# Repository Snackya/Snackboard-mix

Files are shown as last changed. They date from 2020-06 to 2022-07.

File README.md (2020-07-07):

# Snackboard µX - A DIY audio mixer for deej
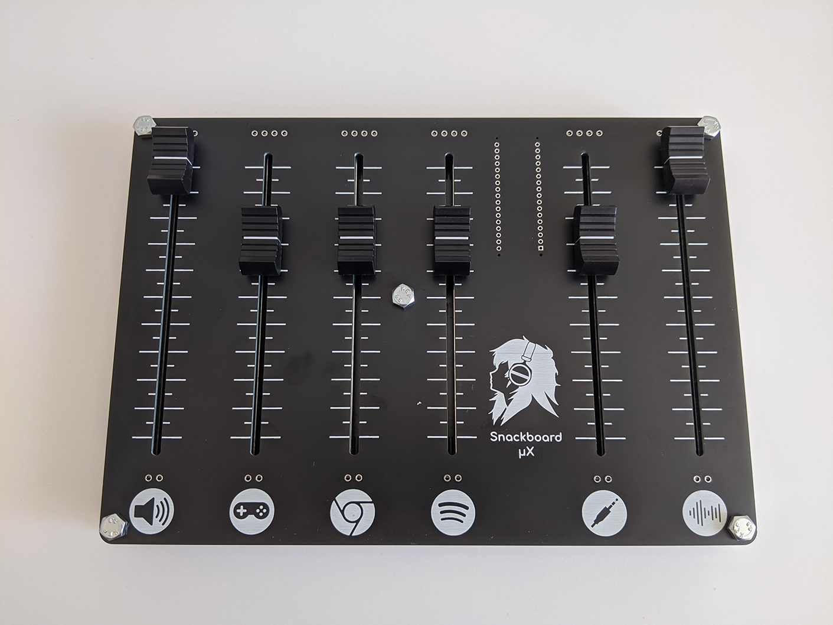
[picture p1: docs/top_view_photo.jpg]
Snackboard photo


## Description
The Snackboard µX (mix/myx) is a PCB to control application volumes on Linux/Windows using [deej](https://github.com/omriharel/deej).
It is powered by an Arduino Micro over USB and utilises 6 sliders to control the audio volume of the software configured in deej. The microcontroller reads the current state via a 10bit ADC and sends a value of 0-1023 to the PC and deej via serial.

The goal of this build was to create a mixer without any need for a 3D-printer, mill or any kind of casing. It takes advantage of the fact, that most PCB manufacturers only ship 5 prototype board minimum and uses one of them for part assembly and another for a faceplate. All the tracks for connecting parts are routed on the bottom copper layer, so the front paste and silk layers stay clean.

## Specifications
- 222 x 156 x 25 mm
- 6 sliders
- powered via Micro-USB
- [deej](https://github.com/omriharel/deej)

## Parts
- 1x Arduino Micro
- 6x Alps sliding potentiometers, linear, RSA0N12-LIN10K (most alps sliders should work. make sure they are linear and have the same footprint)
- 5x M4 bolts
- 20x M4 nuts

## Usage
Just submit the files in /gerber/ to your preferred PCB manufacturer. (Most manufacturers prefer a .zip archive of these files.)

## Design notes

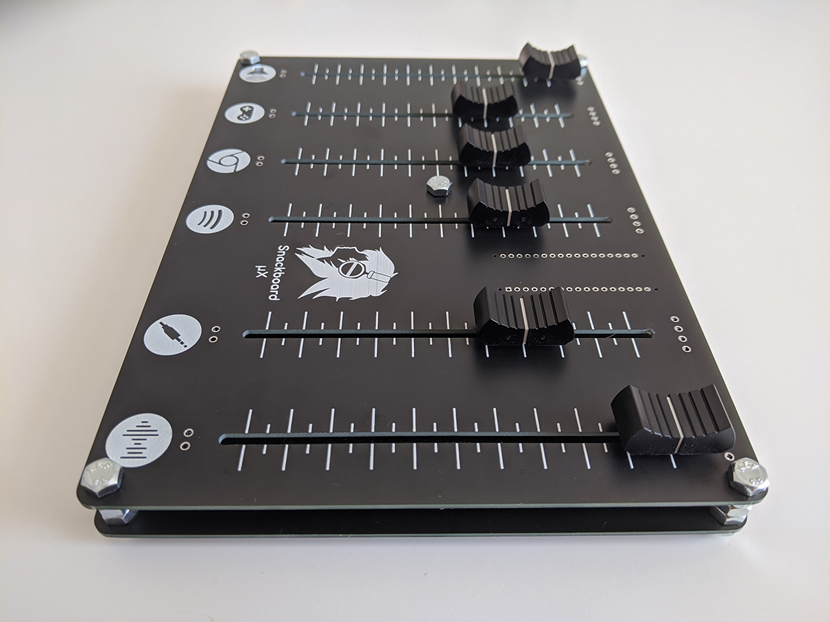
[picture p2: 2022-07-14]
docs/side_view_photo.jpg

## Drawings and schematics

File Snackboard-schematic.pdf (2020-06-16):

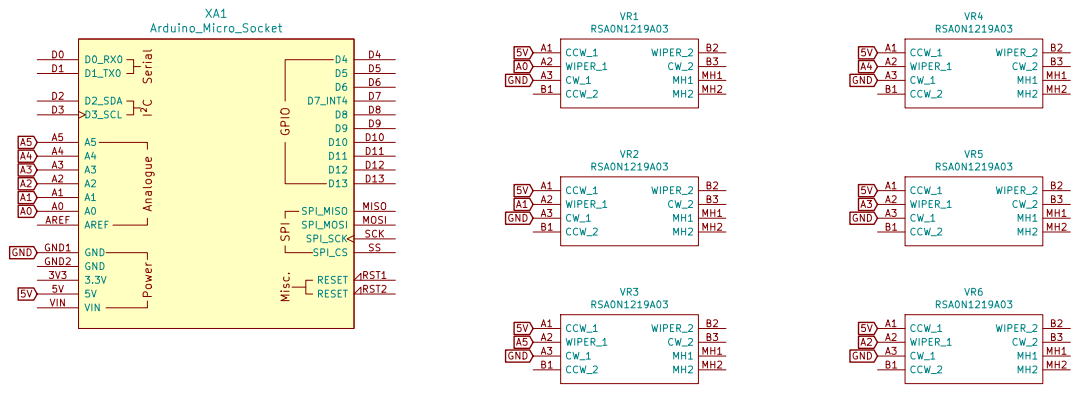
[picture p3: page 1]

Id: 1/1 Title: File: Snackboard.sch Sheet: /

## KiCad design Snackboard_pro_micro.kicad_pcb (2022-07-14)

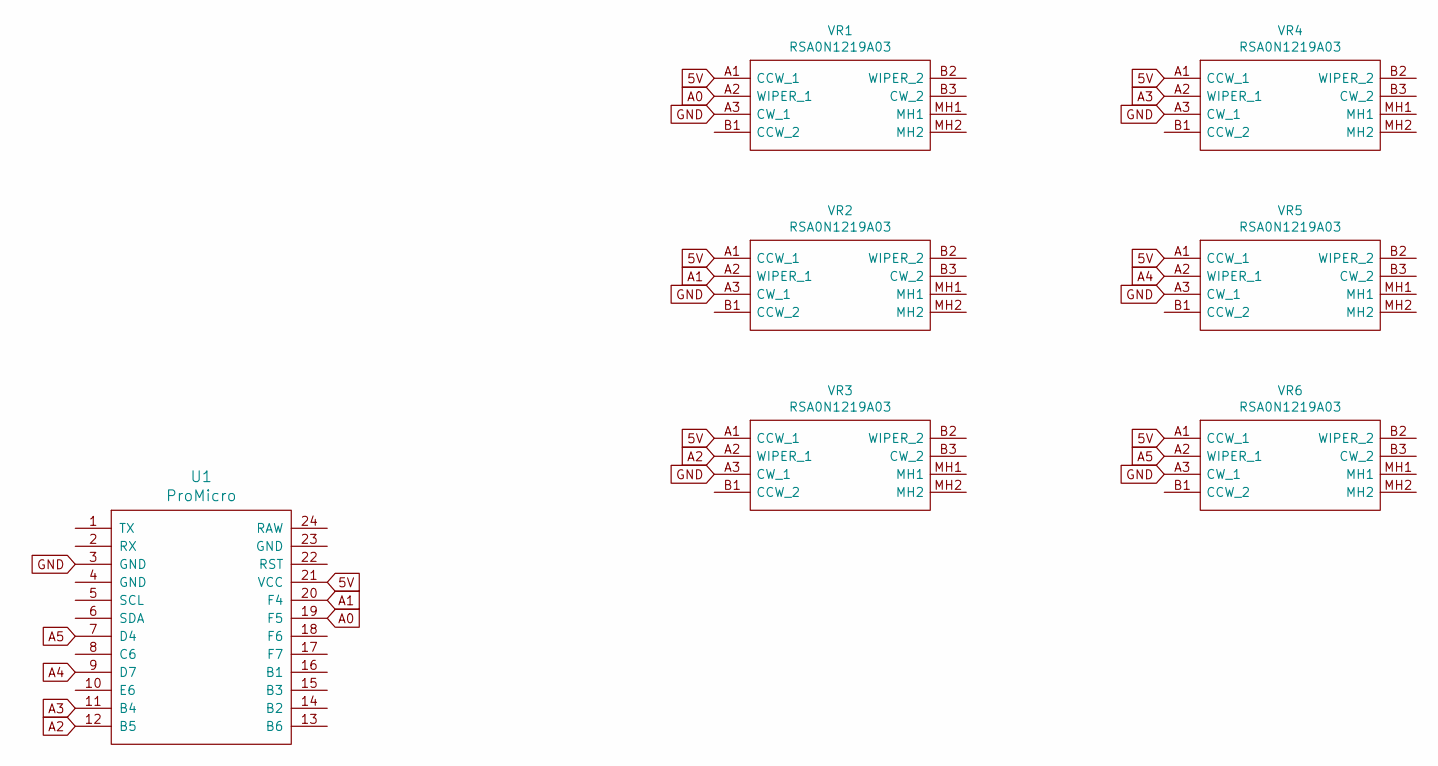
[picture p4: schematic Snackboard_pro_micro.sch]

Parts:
U1: ProMicro
VR1, VR2, VR3, VR4, VR5, VR6: RSA0N1219A03; Mouser Part Number 688-RSA0N1219A03

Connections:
5V: U1.21 (VCC), VR1.A1 (CCW_1), VR2.A1 (CCW_1), VR3.A1 (CCW_1), VR4.A1 (CCW_1), VR5.A1 (CCW_1), VR6.A1 (CCW_1)
A0: U1.19 (F5), VR1.A2 (WIPER_1)
A1: U1.20 (F4), VR2.A2 (WIPER_1)
A2: U1.12 (B5), VR3.A2 (WIPER_1)
A3: U1.11 (B4), VR4.A2 (WIPER_1)
A4: U1.9 (D7), VR5.A2 (WIPER_1)
A5: U1.7 (D4), VR6.A2 (WIPER_1)
GND: U1.3 (GND), VR1.A3 (CW_1), VR2.A3 (CW_1), VR3.A3 (CW_1), VR4.A3 (CW_1), VR5.A3 (CW_1), VR6.A3 (CW_1)

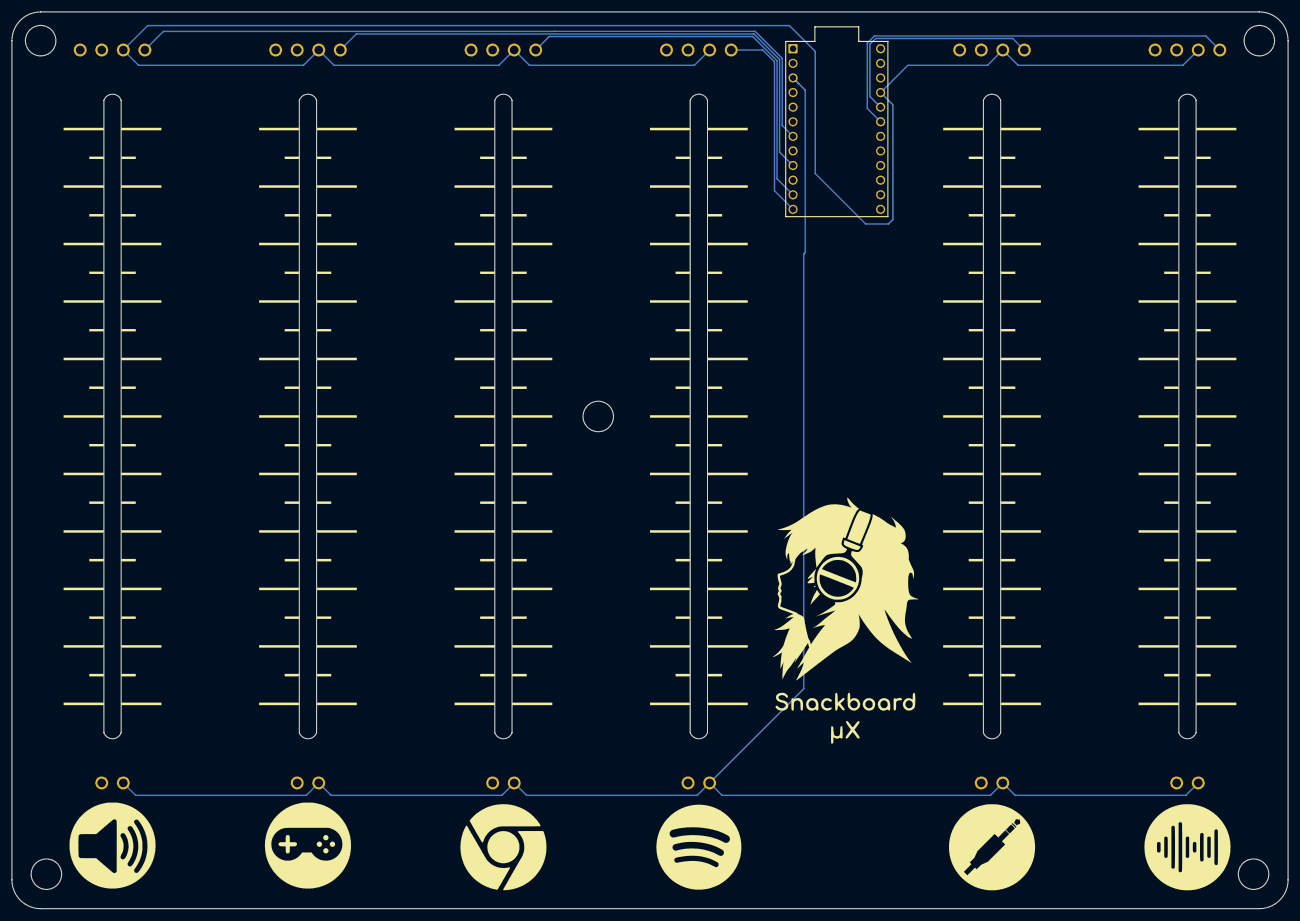
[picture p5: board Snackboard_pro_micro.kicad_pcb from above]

Board: 2 copper layers, 222.0 x 156.0 mm, 7 parts (0 on the bottom side), 8 nets.

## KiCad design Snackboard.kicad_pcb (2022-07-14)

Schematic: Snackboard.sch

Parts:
VR1, VR2, VR3, VR4, VR5, VR6: RSA0N1219A03; Mouser Part Number 688-RSA0N1219A03
XA1: Arduino_Micro_Socket

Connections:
5V: VR1.A1 (CCW_1), VR2.A1 (CCW_1), VR3.A1 (CCW_1), VR4.A1 (CCW_1), VR5.A1 (CCW_1), VR6.A1 (CCW_1), XA1.5V
A0: VR1.A2 (WIPER_1), XA1.A0
A1: VR2.A2 (WIPER_1), XA1.A1
A2: VR6.A2 (WIPER_1), XA1.A2
A3: VR5.A2 (WIPER_1), XA1.A3
A4: VR4.A2 (WIPER_1), XA1.A4
A5: VR3.A2 (WIPER_1), XA1.A5
GND: VR1.A3 (CW_1), VR2.A3 (CW_1), VR3.A3 (CW_1), VR4.A3 (CW_1), VR5.A3 (CW_1), VR6.A3 (CW_1), XA1.GND1

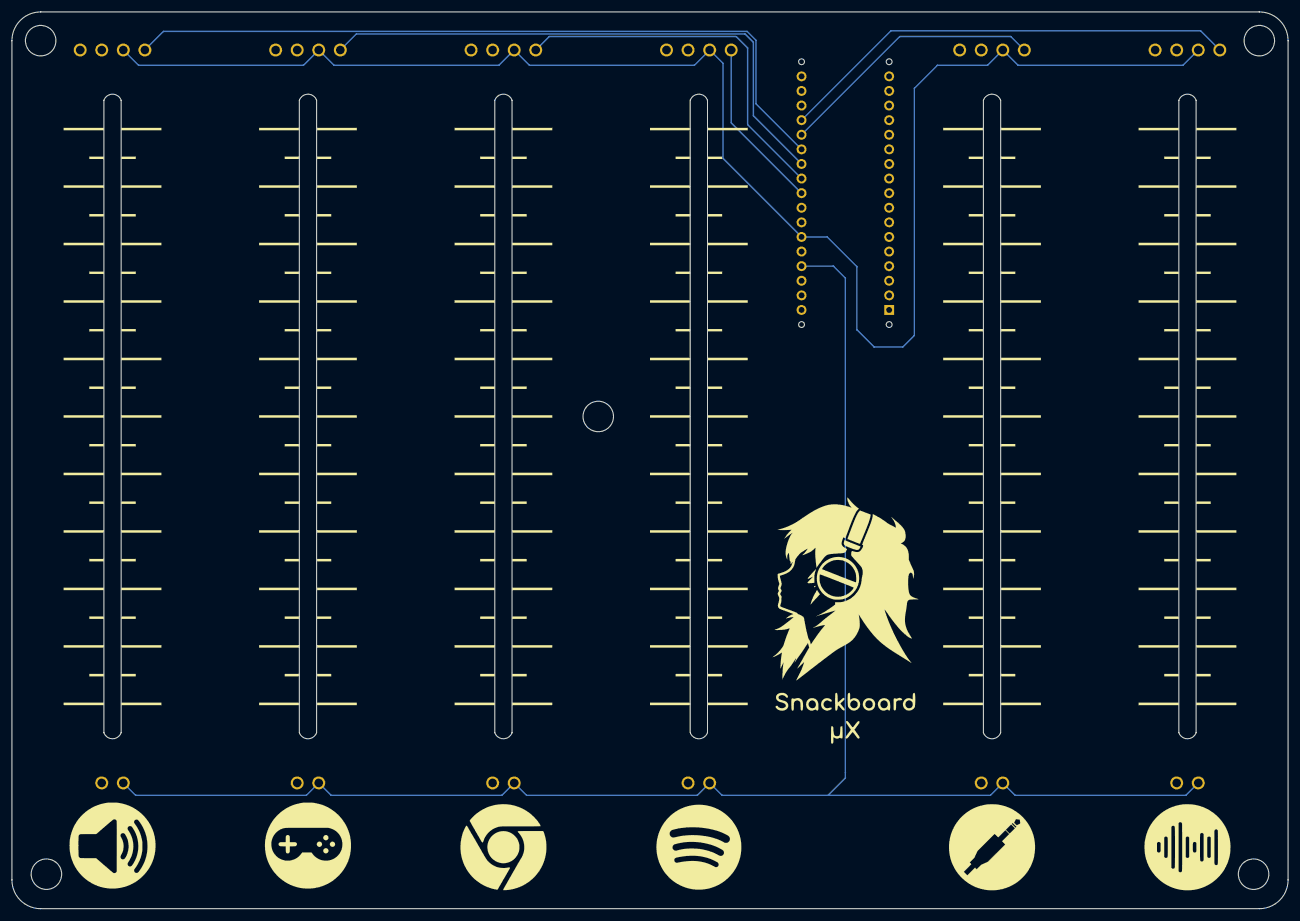
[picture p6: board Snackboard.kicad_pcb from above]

Board: 2 copper layers, 222.0 x 156.0 mm, 7 parts (0 on the bottom side), 8 nets.

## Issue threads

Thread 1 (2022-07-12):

KiCad file

Poechi, 2022-07-12:
Do you have the KiCad project file for this project? I would like different icons below the faders.
Thank you.

Snackya, 2022-07-14:
Sorry for not including them originally. I had to clean up some unused legacy files for licensing reasons first.
KiCad project files have been added as of 3d74514321407cc8a0384599fe86aa4659222d7b .
If you want to replace the icons on the PCB, simply delete the footprint in Pcbnew, convert an image to a .kicad_mod file using KiCad's Bitmap to Component converter and add the resulting file to the PCB.

Closed 2022-07-14.

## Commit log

2020-06-16 Add project files
    added schematic, gerber files and photos
    [Snackboard-B_Cu.gbr, Snackboard-B_Mask.gbr, Snackboard-B_Paste.gbr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]
2020-07-07 Update README.md
    changed parts description, since the Pro version of the Arduino Micro available in overseas retail seems to have a different pinout
2020-07-07 add pro micro version
    - deleted gerber files for paste, since it was unused
    - changed folder structure
    [Snackboard-B_Cu.gbr, Snackboard-B_Mask.gbr, Snackboard-B_Paste.gbr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]
2022-07-14 add KiCAD project files
    [Snackboard.kicad_pcb, Snackboard.sch, Snackboard_pro_micro.kicad_pcb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]
